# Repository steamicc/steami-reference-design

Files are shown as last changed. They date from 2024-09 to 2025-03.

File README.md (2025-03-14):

# STeaMi Reference Design

Welcome to the repository for the **STeaMi Reference Design**. This repository contains all the electronic and mechanical design files for the STeaMi learning board, a versatile and feature-rich platform for teaching programming and electronics.

## Overview
[STeaMi](https://www.steami.cc/) is an educational board aimed at introducing students, educators, and enthusiasts to the basics of programming, electronics, and STEM concepts. The board is designed with simplicity and versatility in mind, providing a powerful platform for learning through hands-on experience.



The **STeaMi board** is built around the **STM32WB55 microcontroller** and is designed to offer:

- **Connectivity:** BLE (Bluetooth Low Energy) communication capabilities.
- **Extensibility:** Integration options with Jacdac and Qwiic connectors.
- **Versatility:** A wide array of onboard sensors.
- **Compatibility:** Seamless integration with the **micro:bit ecosystem**, allowing educators to continue using existing materials while leveraging the advanced capabilities of STeaMi when needed.

This board is an essential tool for educators aiming to explore STEAM (Science, Technology, Engineering, Arts, Mathematics) education.

## Key Features

### Hardware
- **Microcontroller:** STM32WB55 with dual-core architecture (ARM Cortex-M4 and Cortex-M0+).
- **BLE Support:** Bluetooth Low Energy for IoT and wireless communication projects.
- **Connectors:**
  - **Jacdac:** For chaining external modules and simplifying connections.
  - **Qwiic:** For seamless sensor and peripheral integration.
- **Onboard Sensors:**
  - Environmental sensors (temperature, humidity, pressure).
  - Motion sensors (accelerometer, gyroscope, magnetometer).
  - Proximity, light, and other utility sensors.

### Compatibility
- **micro:bit Ecosystem:** Fully compatible, allowing educators to reuse existing peripherals and lessons.
- **Plug-and-play Design:** Simplifies adoption in classrooms and workshops.

### Mechanical Design
- Compact form factor, ensuring ease of use.
- Mounting options compatible with standard educational kits.

## Project Background
The STeaMi board was developed as part of the **I-NOVMICRO** project ([Learn more](https://campus-industriefutur-sud.com/i-novmicro/)) and the **MAGNETICS** project ([Learn more](https://www.magnetics.edu-up.fr/)). These initiatives aim to advance innovative tools for education and training.

## Repository Contents
- **Electronics Design Files:** Schematics, PCB layout files, and BOM.
- **Mechanical Design Files:** CAD models for the enclosure and mounting options.

## Getting Started
1. Clone this repository:
   ```bash
   git clone https://github.com/steamicc/steami-reference-design.git
   ```
2. Review the documentation folder for setup instructions.
3. Open the design files using your preferred CAD and PCB design tools.

## License
All resources in this repository are released under an open license and are protected under the stewardship of the **STeaMi Foundation**. See the `LICENSE` file for more details.

## Contributions
We welcome contributions to enhance the STeaMi board. Whether you’re fixing a bug, adding a feature, or improving documentation, feel free to submit a pull request.

## Resources
- [STeaMi Official Website](https://www.steami.cc/)

## Support
If you have any questions or need assistance, please open an issue in this repository or contact us via [STeaMi contact mail](mailto:contact@steami.cc).

---

Thank you for supporting STeaMi and STEAM education!

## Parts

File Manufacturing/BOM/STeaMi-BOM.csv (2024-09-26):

Description | Quantity | Designator | Manufacturer | Manufacturer Part Number | Part Number | Digikey | Farnell | Mouser | RS | Switch possibility | Layer
CAP CER 1µF 6,3V X5R 0402 | 11 | C1, C2, C10, C12, C31, C46, C47, C62, C63, C77, C80 | Taiyo Yuden | JMK105BJ105KV-F | 1µF-10%-6,3V-X5R-0402 |  |  | 963-JMK105BJ105KV-F |  | True | Bottom, Top
CAP CER 10nF 10V X7R 0402 | 1 | C13 | AVX | 0402ZC103KAT2A | 10nF-10%-10V-X7R-0402 |  |  | 581-0402ZC103KAT2A |  | True | Top
CAP CER 100pF 10V X7R 0402 | 1 | C15 | WURTH Electronics | 885012205001 | 100pF-10%-10V-X7R-0402 | 732-7496-1-ND | 2812288 | 710-885012205001 |  | True | Top
CAP CER 200mF 3,3V Supercap 6,8X11,7x1,8 | 1 | C17 | Elna America | DSK-3R3H204T614-H2L | 200mF-20%-3,3V-Supercap-6,8X11,7x1,8 | 604-1147-1-ND |  | 555-DSK3R3H204T614H2 |  | False | Top
CAP CER 4,7µF 6,3V X5R 0402 | 6 | C25, C32, C34, C55, C57, C86 | Murata | GRM155R60J475ME8D | 4,7µF-20%-6,3V-X5R-0402 | 490-5408-6-ND |  | 81-GRM155R60J475ME8D |  | True | Top, Bottom
CAP CER 15pF 10V C0G 0402 | 4 | C26, C27, C28, C29 | KEMET | C0402C150J8HACTU | 15pF-5%-10V-C0G-0402 |  | 3784148 | 80-C0402C150J8HACTU |  | True | Bottom
CAP CER 47µF 4V X5R 0603 | 2 | C3, C87 | Taiyo Yuden | AMK107BBJ476MA-RE | 47µF-20%-4V-X5R-0603 |  |  | 963-AMK107BBJ476MARE |  | True | Top
CAP CER 10µF 6,3V X5R 0402 | 6 | C4, C8, C52, C64, C83, C84 | Murata | GRM155R60J106ME15D | 10µF-20%-6,3V-X5R-0402 | 490-13238-1-ND | - | 81-GRM155R60J106ME5D | - | True | Top, Bottom
CAP CER 33pF 16V COG 0402 | 1 | C42 | WURTH Electronics | 885012005028 | 33pF-5%-16V-COG-0402 | 732-7444-1-ND |  | 710-885012005028 |  | True | Bottom
CAP CER 4,7µF 16V X5R 0402 | 2 | C44, C45 | Kyocera AVX | 0402YD475MAT2A | 4,7µF-20%-16V-X5R-0402 | 478-10788-1-ND |  | 581-0402YD475MAT2A |  | True | Top
CAP CER 100nF 6,3V X5R 0402 | 38 | C5, C9, C11, C14, C16, C18, C19, C20, C21, C22, C23, C24, C30, C33, C35, C36, C37, C38, C39, C40, C41, C43, C48, C49, C50, C51, C54, C56, C58, C69, C70, C71, C72, C75, C78, C79, C81, C82 | Kyocera AVX | 0402YD104KAT2A | 100nF-10%-6,3V-X5R-0402 | 478-1126-1-ND |  | 581-0402YD104K |  | True | Top, Bottom
CAP CER 220nF 6,3V X7R 0603 | 1 | C53 | KEMET | C0603C224K9RACTU | 220nF-10%-6,3V-X7R-0603 | 399-9046-1-ND |  | 80-C0603C224K9R |  | True | Bottom
CAP CER 470pF 25V X7R 0402 | 1 | C6 | Yageo | AC0402KRX7R8BB471 | 470pF-10%-25V-X7R-0402 |  |  | 603-AC402KRX7R8BB471 |  | True | Top
CAP CER 15µF 25V TANT 1210 | 1 | C7 | Panasonic | 25TQC15MYFB | 15µF-20%-25V-TANT-1210 | P16204CT-ND | 2982721 | 667-25TQC15MYFB |  | True | Top
CAP CER 22pF 16V COG 0402 | 2 | C73, C74 | Murata | GJM0225C1C220JB01L | 22pF-5%-16V-COG-0402 | - | - | 80-C0402C220J4GAUTO | - | True | Bottom
CAP CER 10pF 10V COG 0402 5% | 1 | C85 | WURTH Electronics | 885012005007 | 10pF-5%-10V-COG-0402 |  | 2533781 | 710-885012005007 |  | True | Top
Suppresseurs ESD / diodes TVS WE-TVS High Speed 5uA 5VDC 4+1 | 1 | D1 | Wurth | WE-TVS_824015 | WE-TVS_824015 |  |  | 710-824015 |  | False | Bottom
ESD Suppressors / TVS Diodes Transient Voltage Suppressor PP | 5 | D2, D4, D10, D13, D24 | Diodes Incorporated | D5V0H1B2LP-7B | D5V0H1B2LP-7B | D5V0H1B2LP-7BDICT-ND |  | 621-D5V0H1B2LP-7B |  | False | Top, Bottom
Diode Schottky 40 V 1A Montage en surface SDO-323HE | 1 | D25 | OnSemiconductor | SS14HE | SS14HE | 512-SS14HE | 2929794 |  |  | False | Top
Diode 40 V 100mA Surface Mount 0402C/SOD-923F | 2 | D26, D27 | Comchip | CDBQR0140R-HF | CDBQR0140R-HF | CDBQR0140R-HF-ND |  |  |  | False | Bottom
Diode Schottky 40 V 1A Montage en surface SOD-123 | 1 | D3 | Torex Semiconductor | XBS104S14R-G | XBS104S14R-G |  |  | 865-XBS104S14R-G |  | False | Top
Diode Schottky 30 V 1A Montage en surface SOD-123 | 4 | D5, D6, D7, D15 | SMC diode solutions | MBR130HWTR | MBR130HWTR | 1655-1437-1-ND |  |  |  | False | Top, Bottom
Suppresseurs ESD / diodes TVS LOW CAP SNAPBACK ESD PROT | 13 | D8, D9, D11, D12, D14, D16, D17, D18, D19, D20, D21, D22, D23 | OnSemiconductor | ESD8351XV2T1G | ESD8351XV2T1G |  | 2770609 | 863-ESD8351XV2T1G |  | False | Bottom, Top
Fusible 50V 1,25 A Slow blow | 1 | F1 | Bourns | SF-0603SP125-2 | SF-0603SP125-2 |  |  | 652-SF-0603S125-2 |  | False | Top
Chip Ferrite Bead 300 ohm à 100MHZ | 1 | FB1 | WURTH | 742792641 | 742792641 |  |  | 710-742792641 |  | False | Bottom
Chip Ferrite Bead 330 ohm à 100MHZ | 1 | FB2 | MURATA | BLM18RK102SN1D | BLM18RK102SN1D | 490-5228-1-ND |  | 81-BLM18RK102SN1D |  | False | Bottom
CONN header smd 2 positions 1,25 mm | 1 | J1 | Amphenol | 10114830-10102LF | 1011483010102LF |  |  | 609-5378-1-ND |  | False | Bottom
Connector micro USB Bottom-SMT No Peg | 1 | J2 | GCT | USB3080-30-00-A | USB3080-30-00-A |  |  | 640-USB3080-30-00-A |  | False | Bottom
Connecteur, embase Montage en surface à angle droit 4 positions (2,00mm) | 2 | J3, J4 | JST | S4B-PH-SM4-TB(LF)(SN) | S4B-PH-SM4-TB(LF)(SN) | 455-1751-1-ND | 9492631 |  |  | False | Bottom
FFC/FPC connector 0,50 Pitch Slider Right angle TOP Contact | 1 | J7 | Molex | 52435-2471 | 52435-2471 |  |  | 538-52435-2471 | 52435-2471-TR250 | False | Top
Common mode chokes | 1 | L1 | WURTH | 744230900 | 744230900 | 732-2582-1-ND |  |  |  | False | Bottom
Fixed Inductor 10µH ± 20% 1,4A 3x3x1,2mm | 1 | L2 | TDK | VLS3012CX-2R2M-1 | 2,2µH-20%-1,89A-74 mOhms |  |  | 810-VLS3012CX-2R2M-1 |  | False | Top
Fixed Inductor 10µH ± 20% 1,4A 5,8mm | 1 | L3 | Wurth | 74404043150A | 15µH-20%-0,84-132 mOhms% | 732-10760-1-ND |  | 710-74404043150A |  | False | Top
Fixed Inductor 10µH µH ± 20% 0,1A 0805 | 1 | L4 | Murata Electronics | LQM21FN100M70L | 10µH-20%-0,1A-600mOhm |  |  | 81-LQM21FN100M70L |  | False | Bottom
Fixed Inductor 10µH ± 20% 1,12A 3x3x1,2mm | 1 | L5 | TDK | VLS3012CX-100M-1 | 10µH-20%-1,12A-324mOhms |  | 3212546 | 810-VLS3012CX-100M-1 |  | False | Top
DEL standard - CMS WL-SMCW SMDMono TpVw Waterclr 0603 RED | 1 | LED2 | WURTH | 150060RS75000 | 150060RS75000 |  |  | 710-150060RS75000 |  | False | Top
DEL standard - CMS WL-SMCW SMDMono TpVw Waterclr 0603 Blue | 2 | LED3, LED6 | WURTH | 150060BS75000 | 150060BS75000 |  |  | 710-150060BS75000 |  | False | Top
LED GREEN 2V 20mA 0603 SMD | 1 | LED4 | WURTH | 150060VS75000 | 150060VS75000 |  |  | 710-150060VS75000 |  | False | Top
LED BI Green Red 2mm x 1,25mm SMD | 1 | LED5 | Kingbright | APHBM2012LSURKZGKC | APHBM2012LSURKZGKC |  |  | 604-APHBM2012LSURKZG |  | False | Top
DEL standard - CMS WL-SFTW SMD TOP SMD 5050 RGB | 1 | LED7 | WURTH | 150505M173300 | 150505M173300 | 150505M173300 |  | 710-150505M173300 |  | False | Top
Speakers & Transducers SURFACE MOUNT TRANSDUCER 3.6 VP-P | 1 | LS1 | PUI Audio Inc | SMT-0825-S-HT-R | SMT-0825-S-HT-R | 668-SMT-0825-S-HT-RCT-ND |  | 665-SMT0825SHTR |  | False | Bottom
RES CMS 1,5K1%-0,0625W-0402 ±100ppm/°C | 1 | R100 | Yageo | RC0402FR-071K5L | 1,5K-1%-0,0625W-0402 | 311-1.50KLRDKR-ND | 2693583 | 603-RC0402FR-071K5L |  | True | Bottom
RES CMS 100K1%-0,063W-0402 ±100ppm/°C | 1 | R116 | TE Connectivity | CRG0402F100K | 100K-1%-0,063W-0402 |  |  |  | 667-8977 | True | Top
RES CMS 10K1%-0,0625W-0402 ±100ppm/°C | 6 | R12, R19, R26, R28, R91, R96 | Yageo | AC0402FR-1310KL | 10K-1%-0,0625W-0402 |  |  | 603-AC0402FR-1310KL |  | True | Bottom, Top
RES CMS 1,6K1%-0,1W-0402 ±100ppm/°C | 2 | R13, R14 | Panasonic | ERJ-2RKF 1601X | 1,6K-1%-0,1W-0402 |  |  | 667-ERJ-2RKF1601X |  | True | Bottom
RES CMS 4,7K5%-0,0625W-0402 ±100ppm/°C | 9 | R15, R16, R33, R34, R35, R36, R37, R38, R39 | Yageo | AC0402JR-074K7L | 4,7K-5%-0,0625W-0402 | 311-4.7KLBDKR-ND | 3495221 | 603-AC0402JR-074K7L |  | True | Bottom, Top
RES CMS 10m1%-0,2W-0402 ±0ppm/°C | 1 | R18 | Panasonic | ERJ-2LWFR010X | 10m-1%-0,2W-0402 |  |  | 667-ERJ-2LWFR010X |  | False | Bottom
RES CMS 100K5%-0,0625W-0402 ±100ppm/°C | 8 | R2, R5, R8, R17, R69, R99, R105, R110 | Yageo | RC0402JR-07100KL | 100K-5%-0,0625W-0402 | 311-100KJRCT-ND | 9233008 |  |  | True | Bottom
RES CMS 100R5%-0,0625W-0402 ±100ppm/°C | 11 | R21, R40, R41, R42, R43, R44, R45, R46, R65, R93, R97 | Yageo | RC0402JR-07100RL | 100R-5%-0,0625W-0402 | 311-100JRCT-ND | 9232648 |  |  | True | Top, Bottom
RES CMS 1M1%-0,125W-0402 ±0ppm/°C | 2 | R22, R56 | Yageo | RC0402FR-7W1ML | 1M-1%-0,125W-0402 |  |  | 603-RC0402FR-7W1ML |  | True | Top
RES CMS 178K1%-0,1W-0402 ±25ppm/°C | 1 | R23 | Panasonic | ERJ-2RKF1783X | 178K-1%-0,1W-0402 |  |  | 667-ERJ-2RKF1783X |  | True | Top
RES CMS 105K0,5%-0,1W-0402 ±0ppm/°C | 1 | R27 | Panasonic | ERJ-2RKF1053X | 105K-0,5%-0,1W-0402 |  | 2302841 | 667-ERJ-2RKF1053X |  | True | Top
RES CMS 15R0,5%-1W-1206 ±0ppm/°C | 1 | R31 | Susumu | HRG3216Q-15R0-D-T1 | 15R-0,5%-1W-1206 | 408-1885-1-ND |  | 754-HRG3216Q15R0DT1 |  | True | Top
RES CMS 0R5%-0,0625W-0402 | 27 | R4, R6, R10, R11, R20, R24, R25, R30, R48, R49, R50, R52, R60, R62, R68, R71, R72, R73, R74, R79, R83, R94, R95, R111, R112, R113, R114 | Yageo | RC0402JR-100RL | 0R-5%-0,0625W-0402 |  |  | 603-RC0402JR-100RL |  | True | Bottom, Top
RES CMS 220R5%-0,1W-0402 ±10ppm/°C | 1 | R47 | Panasonic | ERJ-2GEJ221X | 220R-5%-0,1W-0402 | P220JCT-ND | 2692419 | 667-ERJ-2GEJ221X |  | True | Bottom
RES CMS 470R5%-0,1W-0402 ±200ppm/°C | 1 | R53 | Panasonic | ERJ-2GEJ471X | 470R-5%-0,1W-0402 |  |  | 667-ERJ-2GEJ471X |  | True | Bottom
RES CMS 10R1%-0,0625W-0402 ±200ppm/°C | 6 | R54, R64, R66, R67, R106, R108 | Yageo | RC0402FR-1010RL | 10R-1%-0,0625W-0402 |  |  | 603-RC0402FR-1010RL |  | True | Top
RES CMS 120R1%-0,0625W-0402 ±200ppm/°C | 2 | R55, R58 | Yageo | AC0402FR-07120RL | 120R-1%-0,0625W-0402 | YAG3440CT-ND |  | 603-AC0402FR-07120RL |  | True | Top
RES CMS 1,15M1%-0,1W-0402 ±0ppm/°C | 1 | R57 | KOA Speer | RK73H1ETTP1154F | 1,15M-1%-0,1W-0402 | 2019-RK73H1ETTP1154FCT-ND |  | 660-RK73H1ETTP1154F |  | True | Top
RES CMS 324K1%-0,0625W-0402 ±100ppm/°C | 1 | R59 | Yageo | AC0402FR-07324KL | 324K-1%-0,0625W-0402 | 13-AC0402FR-07324KLCT-ND |  | 603-AC0402FR-07324KL |  | True | Top
RES CMS 47R1%-0,0625W-0402 ±100ppm/°C | 1 | R61 | Yageo | RC0402FR-0747RL | 47R-1%-0,0625W-0402 | 311-47.0LRCT-ND |  | 603-RC0402FR-0747RL | 198-7801 | True | Top
RES CMS 100K1%-0,1W-0402 ±100ppm/°C | 3 | R63, R102, R103 | Panasonic | ERJ-2RKF1003X | 100K-1%-0,1W-0402 |  |  | 667-ERJ-2RKF1003X |  | True | Bottom
RES CMS 0R 1% 0,1W 0603 ±100ppm/°C | 1 | R81 | Vishay | CRCW06030000Z0EAC | 0R-1%-0,1W-0603 | 541-4012-1-ND | - | 71-CRCW06030000Z0EAC | - | True | Bottom
RES CMS 22R0,5%-0,0625W-0402 ±100ppm/°C | 1 | R86 | Panasonic | ERJ2RKD22R0X | 22R-0,5%-0,0625W-0402 |  |  | 667-ERJ-2RKD22R0X |  | True | Bottom
RES CMS 100K1%-0,1W-0603 ±100ppm/°C | 1 | R89 | Yageo | RC0603FR-07100KL | 100K-1%-0,1W-0603 |  |  | RC0603FR-07100KL |  | True | Bottom
RES CMS NI0%-0W-0402 ±100ppm/°C | 2 | R90, R101 | NC | NC | NC-0%-0W-0402 | - | - | - | - | True | Bottom
RES CMS 36K1%-0,0625W-0402 ±100ppm/°C | 1 | R98 | Yageo | RC0402FR-0736KL | 36K-1%-0,0625W-0402 | 311-36.0KLRCT-ND |  | 603-RC0402FR-0736KL |  | True | Bottom
Surface Mounting Switch | 1 | SW1 | C&K | PTS636 SM25J SMTR LFS | PTS636 SM25J SMTR LFS | CKN12325-1-ND |  | 611-PTS636SM25JSMTRL |  | False | Bottom
4-direction type with center-push function | 1 | SW2 | ALPS | SKRHABE010 | SKRHABE010 |  |  | 688-SKRHAB |  | False | Top
Interrupteurs de contact 50mA 12VDC, 1.8N 3.8mm H, G leads | 3 | SW3, SW4, SW5 | C&K | PTS647SM38SMTR2LFS | PTS647SM38SMTR2LFS |  |  | 611-PTS647SM38SMTR2L |  | False | Top
Small-Signal-Transitor MOSFET N | 2 | T1, T2 | Infineon | BSS119N-H6327 | BSS119N | BSS119NH6327XTSA1CT-ND | - | 726-BSS119NH6327 | - | False | Bottom
Transistors bipolaires - BJT SS SOT23 NPN 40V | 1 | T3 | On Semiconductor | MMBT2222A-7-F | MMBT2222A | MMBT2222A-FDICT-ND | 1773626 |  |  | False | Bottom
MOSFET N/P-CH 60V/50V SOT363 | 1 | T4 | Diodes Incorporated | BSS8402DW-7-F | BSS8402DW-7-F | BSS8402DW-FDIDKR-ND |  |  |  | False | Bottom
Standalone 1 cell 1,5A batterry with PowerPath | 1 | U1 | Texas Instruments | BQ24075RGT | BQ24075RGT |  |  | 595-BQ24075RGTR |  | False | Bottom
Accéléromètre, gyroscope, température, 6 axes Anturi I²C, SPI Sortie | 1 | U10 | STMicroelectronics | ISM330DLCTR | ISM330DLCTR | 497-17583-2-ND |  |  |  | False | Bottom
SENSOR OPTICAL 4M I2C | 1 | U11 | STMicroelectronics | VL53L1CXV0FY/1 | VL53L1X | 497-17764-1-ND |  | 511-VL53L1CXV0FY/1 |  | False | Top
Capteur de pression 3,77PSI ~ 18,27PSI (26kPa ~ 126kPa) Absolu 24 b 10-WFLGA | 1 | U12 | Wurth Elektronik | 2511020213301 | 2511020213301 | 1917-2511020213301CT-ND |  |  |  | False | Top
Humidité, température Capteur I²C, SPI Sortie | 1 | U13 | Wurth Elektronik | 2525020210001 | 2525020210001 | 1917-2525020210001CT-ND |  |  |  | False | Bottom
Capteurs optiques Ambiant 560nm I²C Module 8-SMD | 1 | U15 | Broadcom Limited | APDS-9960 | APDS-9960 | 516-3480-1-ND |  | 630-APDS-9960 |  | False | Top
ARM® Cortex®-M3 STM32F1 Microcontrôleurs IC 32-Bit 72MHz 128Ko (128K x 8) FLASH | 1 | U17 | STMicroelectronics | STM32F103CBT6 | STM32F103CBT6 | 497-6288-ND |  | 511-STM32F103CBT6 |  | False | Bottom
PMIC - Régulateurs de tension - Linéaires Positif Fixe 1 Sortie 150mA SOT-23-5 | 1 | U19 | STMicroelectronics | LD3985M33R | LD3985M33R | 497-3504-1-ND |  | 6868802P |  | False | Bottom
LiCoO2, Li-Ion, Indicateur de charge batterie, alimentation 2.45 V à 4.5 V, interface I2C, SON-12 | 1 | U2 | Texas Instruments | BQ27441DRZR-G1A | BQ27441DRZR-G1A | 296-37271-1-ND | 2400942 | 595-BQ27441DRZR-G1A |  | False | Bottom
FLASH - NOR Mémoire IC 64Mb (8M x 8) SPI - I/O quadruple, QPI, DTR 133MHz 6ns 8-WSON (6x5) | 1 | U20 | Winbond | W25Q64JVZPIM | W25Q64JVZPIM | 256-W25Q64JVZPIM-ND |  |  |  | False | Bottom
5,5V Low loss Power distribution switch | 1 | U21 | DIOO Microcircuits | DIO7003LEST5 | DIO7003LEST5 |  |  | 453-DIO7003LEST5 |  | False | Bottom
Survolteur Régulateur à découpage IC Positif Réglable 1,23V 1 Sortie 75mA (Commutateur) SC-74A, SOT-753 | 1 | U22 | Diodes Incorporated | AP3015AKTR-G1 | AP3015AKTR-G1 | AP3015AKTR-G1DICT-ND |  |  | 8287438 | False | Top
High Efficient single inductor buck-boost converter with 1,8-A switches ajustable | 1 | U3 | Texas Instruments | TPS63000DRCT | TPS63000 |  |  | 595-TPS63000DRCR |  | False | Top
Simple Switcher 24Vout 2,1A Step-Up SOT-23 | 1 | U4 | Texas Instruments | LMR62421XMF_NOPB | LMR62421XMF_NOPB |  |  | 926-LMR62421XMF/NOPB |  | False | Top
MEMS audio sensor omnidirectional digital microphone dor industrial application | 1 | U5 | STMicroelectronics | IMP34DT05 | IMP34DT05 |  |  | 511-IMP34DT05TR |  | False | Top
MCU 32bit, STM32WB55RX-M4, 256 Kb to 1Mb Flash 128 to 256kB SRAM 64MHz Bluetooth 5.2, VFQFPN68 | 1 | U6 | STMicroelectronics | STM32WB55RG | STM32WB55RG |  |  | 511-STM32WB55RGV6 |  | False | Bottom
Centre 2,45GHz fréquence Passe-bas Filtres RF (Fréquence radio) 100MHz Bande passante 1,1dB 6-SMD, sans plomb | 1 | U7 | STMicroelectronics | MLPF-WB55-01E3 | MLPF-WB55-01E3 | 497-19088-1-ND |  | 511-MLPF-WB55-01E3 |  | False | Bottom
Interface - Extensions d'E/S 8B I/O Expander I2C interface | 1 | U8 | Microchip | MCP23009-E/MG | MCP23009-E/MG |  |  | 579-MCP23009-E/MG |  | False | Bottom
magnétorésistif Capteur X, Y, Z axe 12-LGA (2x2) | 1 | U9 | STMicroelectronics | LIS2MDLTR | LIS2MDLTR | 497-17588-2-ND |  |  |  | False | Bottom
QUARTZ 32MHz 9pF 10 ppm | 1 | X1 | Wurth | 830103552209 | 830103552209 | 1923-830103552209CT-ND |  | 710-830103552209 |  | False | Bottom
QUARTZ 32Khz 12pF 30 ppm | 1 | X2 | Wurth | 830062558 | 830062558 | 732-830062558CT-ND |  | 710-830062558 |  | False | Bottom
QUARTZ 8MHz 12pF 20 ppm | 1 | X4 | Wurth | 830108313809 | 830108313809 | 732-830108313809CT-ND |  | 710-830108313809 |  | False | Bottom
Non câblé
NI | 17 | R3, R7, R9, R29, R32, R51, R70, R75, R76, R77, R78, R82, R85, R92, R107, R109, R115 | - | - | NI-1%-0,1W-0603 | - | - | - | - | True | Bottom, Top
Embase FTS 10 point 1,27 mm vertical | 1 | J8 | SAMTEC | FTS-105-01-F-D | FTS-105-01-F-D | SAM9420-ND |  | 200-FTS10501FD |  | False | Top
CONN HEADER VERT 3POS 1.27MM | 1 | J9 | SAMTEC | FTS-103-01-F-S | FTS-103-01-F-S | 612-FTS-103-01-F-S-ND |  |  |  | False | Bottom
RES CMS NI0%-0W-0402 ±100ppm/°C | 2 | R90, R101 | NC | NC | NC-0%-0W-0402 | - | - | - | - | True | Bottom

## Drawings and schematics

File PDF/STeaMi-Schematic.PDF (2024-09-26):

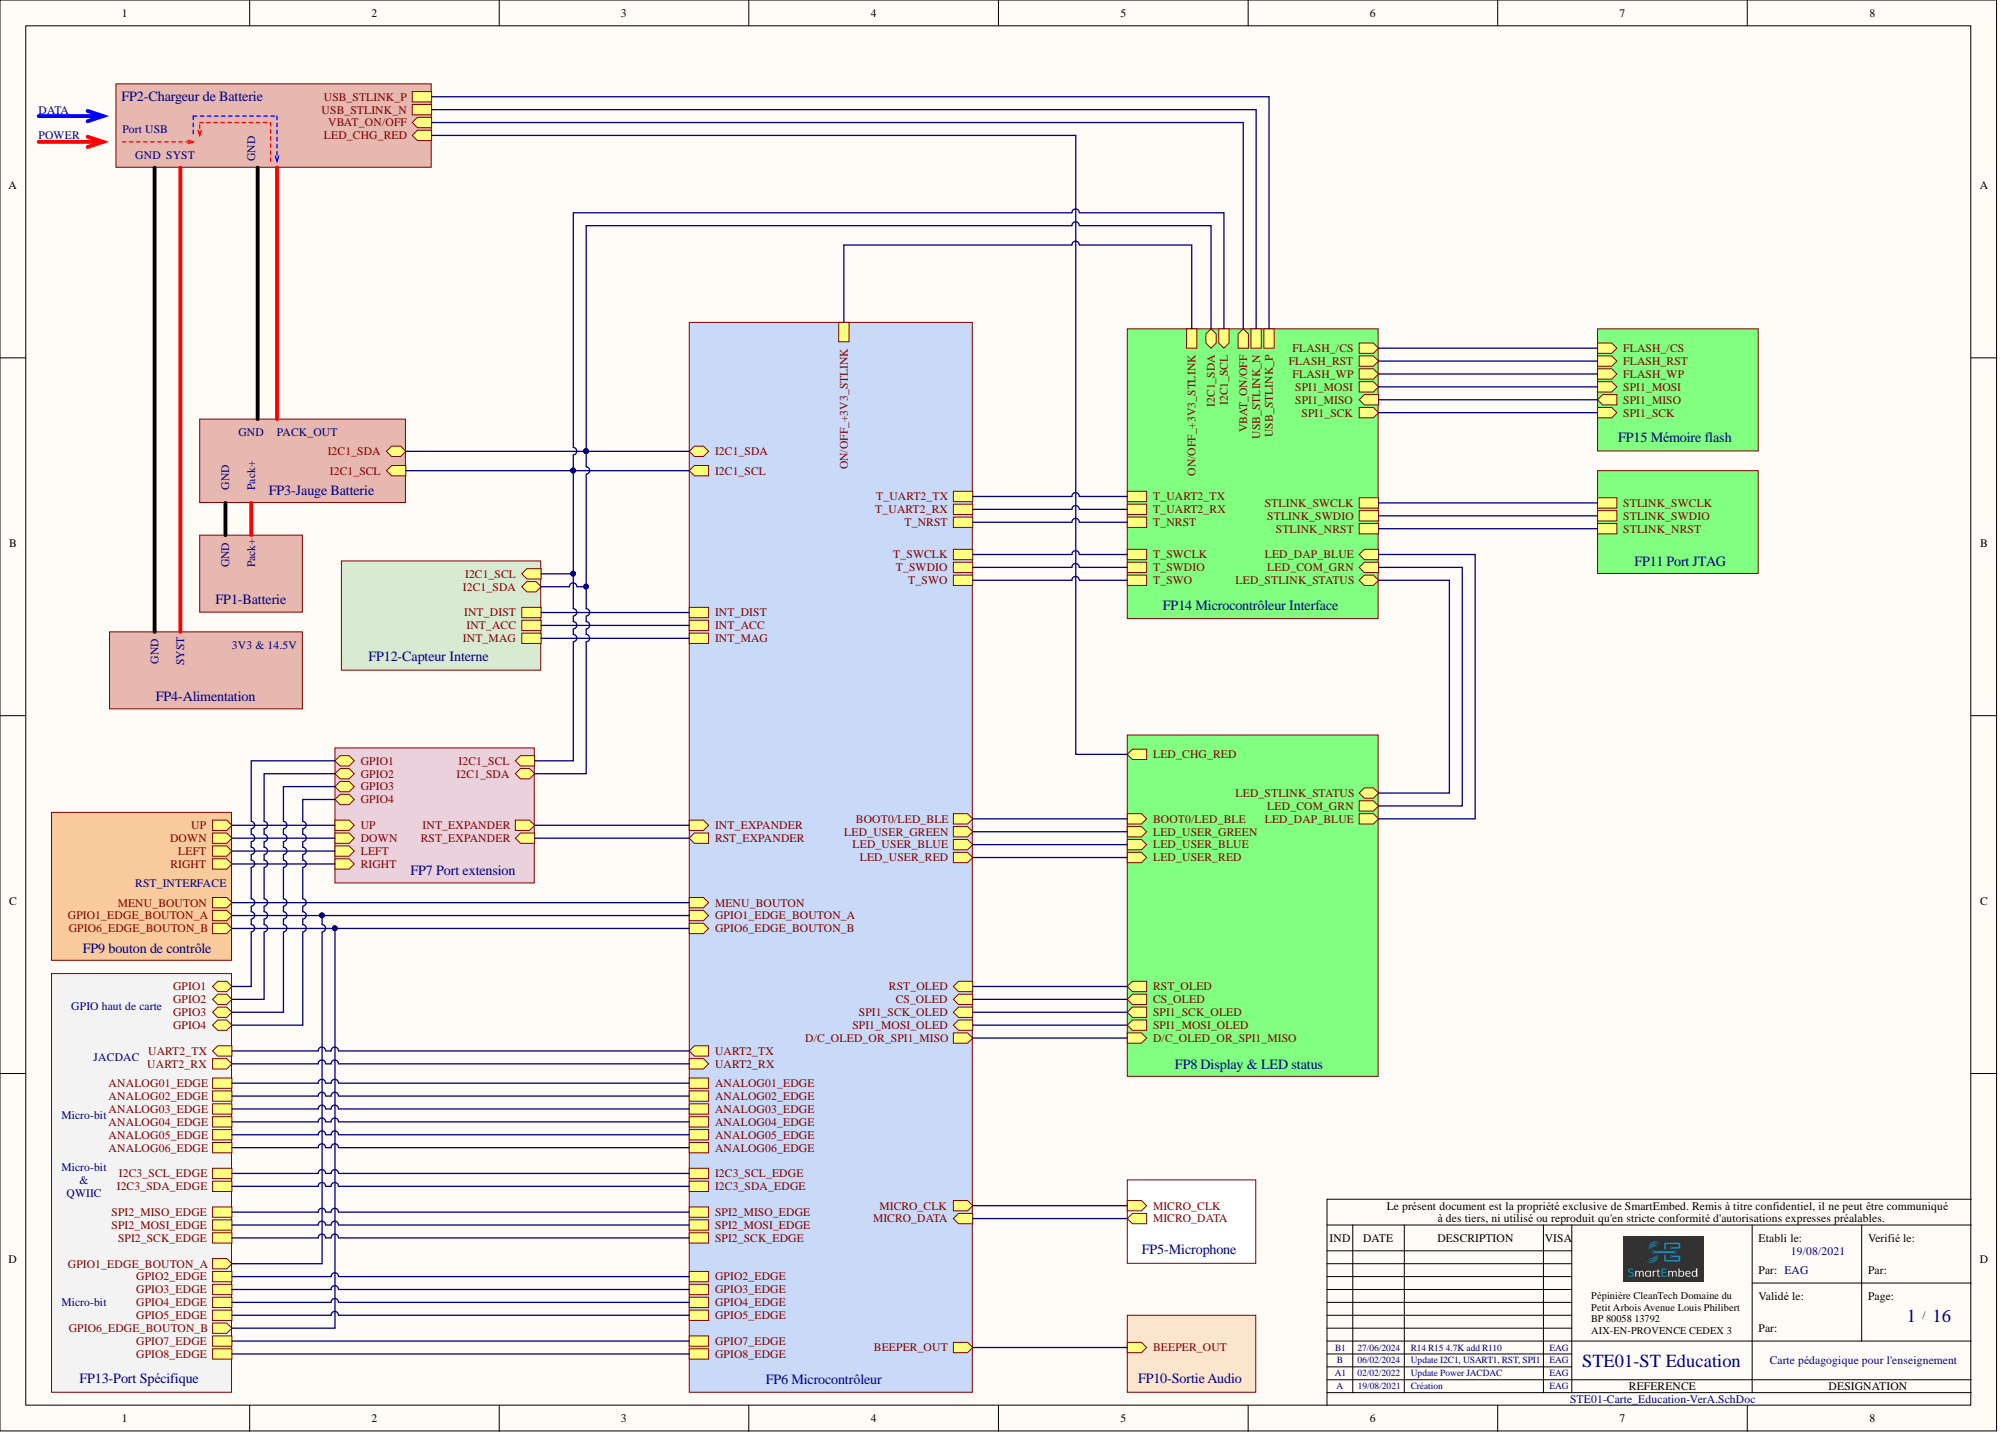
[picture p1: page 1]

GPIO1 GPIO2 GPIO haut de carte GPIO3 GPIO4 UART2_TX JACDAC UART2_RX QWIIC GPIO1_EDGE_BOUTON_A GPIO6_EDGE_BOUTON_B FP13-Port Spécifique

Le présent document est la propriété exclusive de SmartEmbed. Remis à titre confidentiel, il ne peut être communiqué

à des tiers, ni utilisé ou reproduit qu'en stricte conformité d'autorisations expresses préalables.

Pépinière CleanTech Domaine du
Petit Arbois Avenue Louis Philibert
AIX-EN-PROVENCE CEDEX 3

Validé le: Par: | Page: /

B1 | 27/06/2024 | R14 R15 4.7K add R110 | EAG | STE01-ST Education | Carte pédagogique pour l'enseignement
B | 06/02/2024 | Update I2C1, USART1, RST, SPI1 | EAG
A1 | 02/02/2022 | Update Power JACDAC | EAG
A | 19/08/2021 | Création | EAG | REFERENCE | DESIGNATION

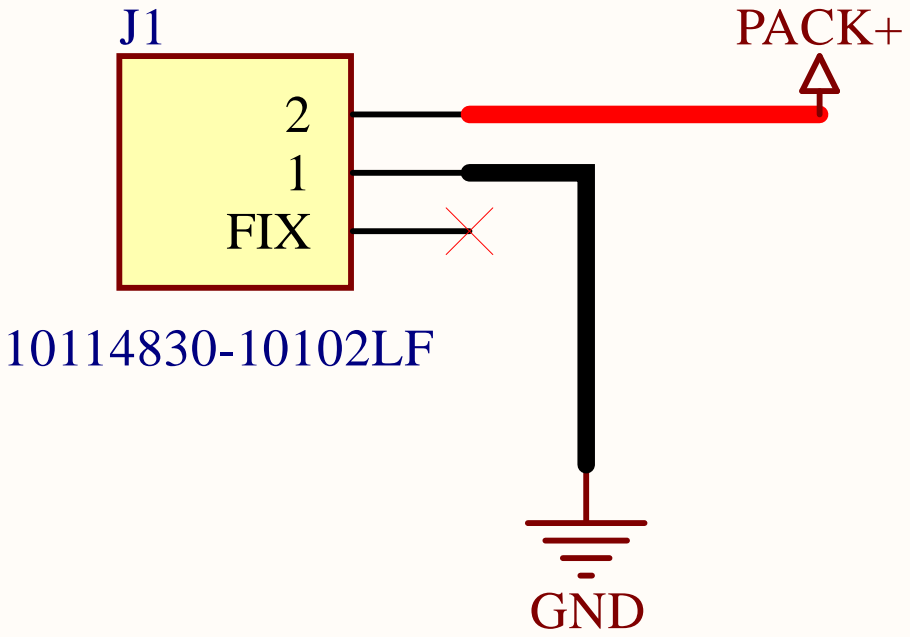
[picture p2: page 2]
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

à des tiers, ni utilisé ou reproduit qu'en stricte conformité d'autorisations expresses préalables.

Pépinière CleanTech Domaine du
Petit Arbois Avenue Louis Philibert

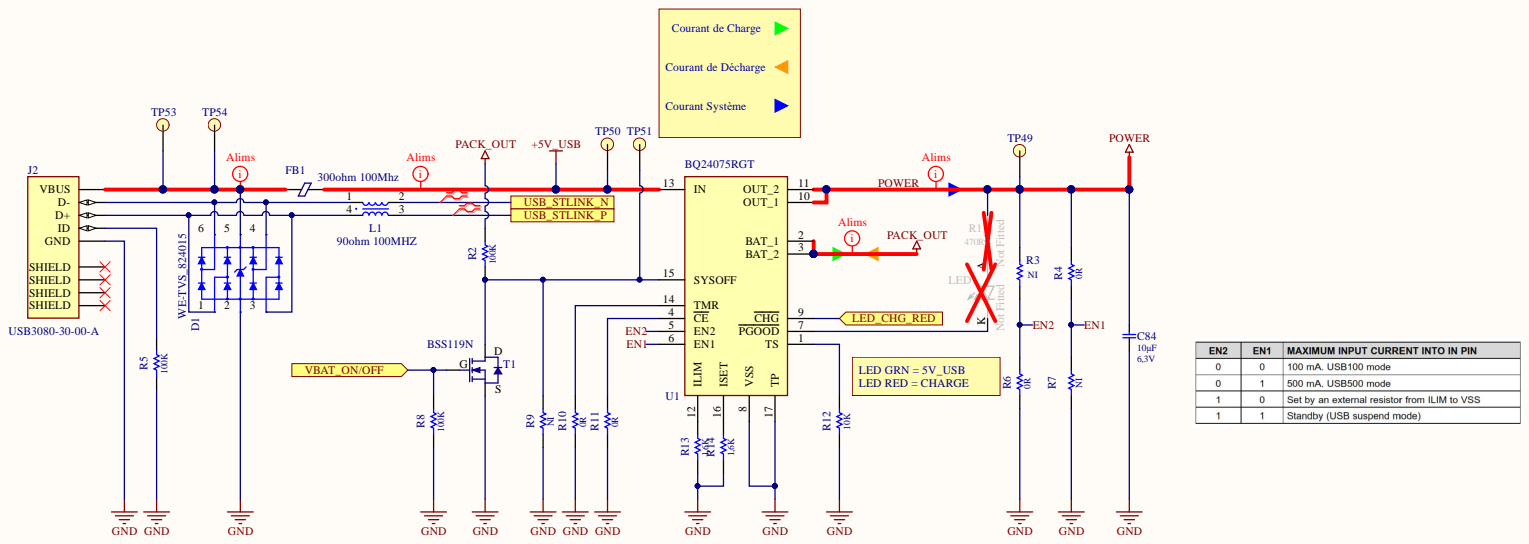
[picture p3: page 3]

1 4

Val i d é le: | Page:

B 1 | 27/06/2024 | R14 R15 4.7K add R | EAG | STE0 1-ST Ed ucatio n | Carte p é dag o g i q ue p o ur l'en sei g nemen t
B | 06/02/2024 | Update I2C1, USART1, R S T , S P I | EAG
A1 | 02/02/2022 | Update Powe r JACDAC | EAG
A | 19/08/2021 | C r é ation | EAG | REFERE NCE | D ESIG N ATIO N

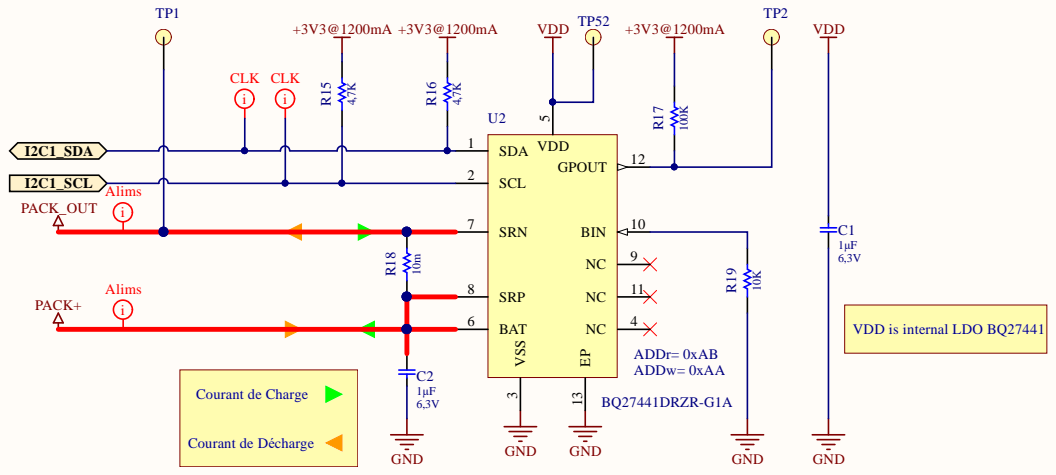
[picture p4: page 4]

Val i d é le: | Page: N4

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

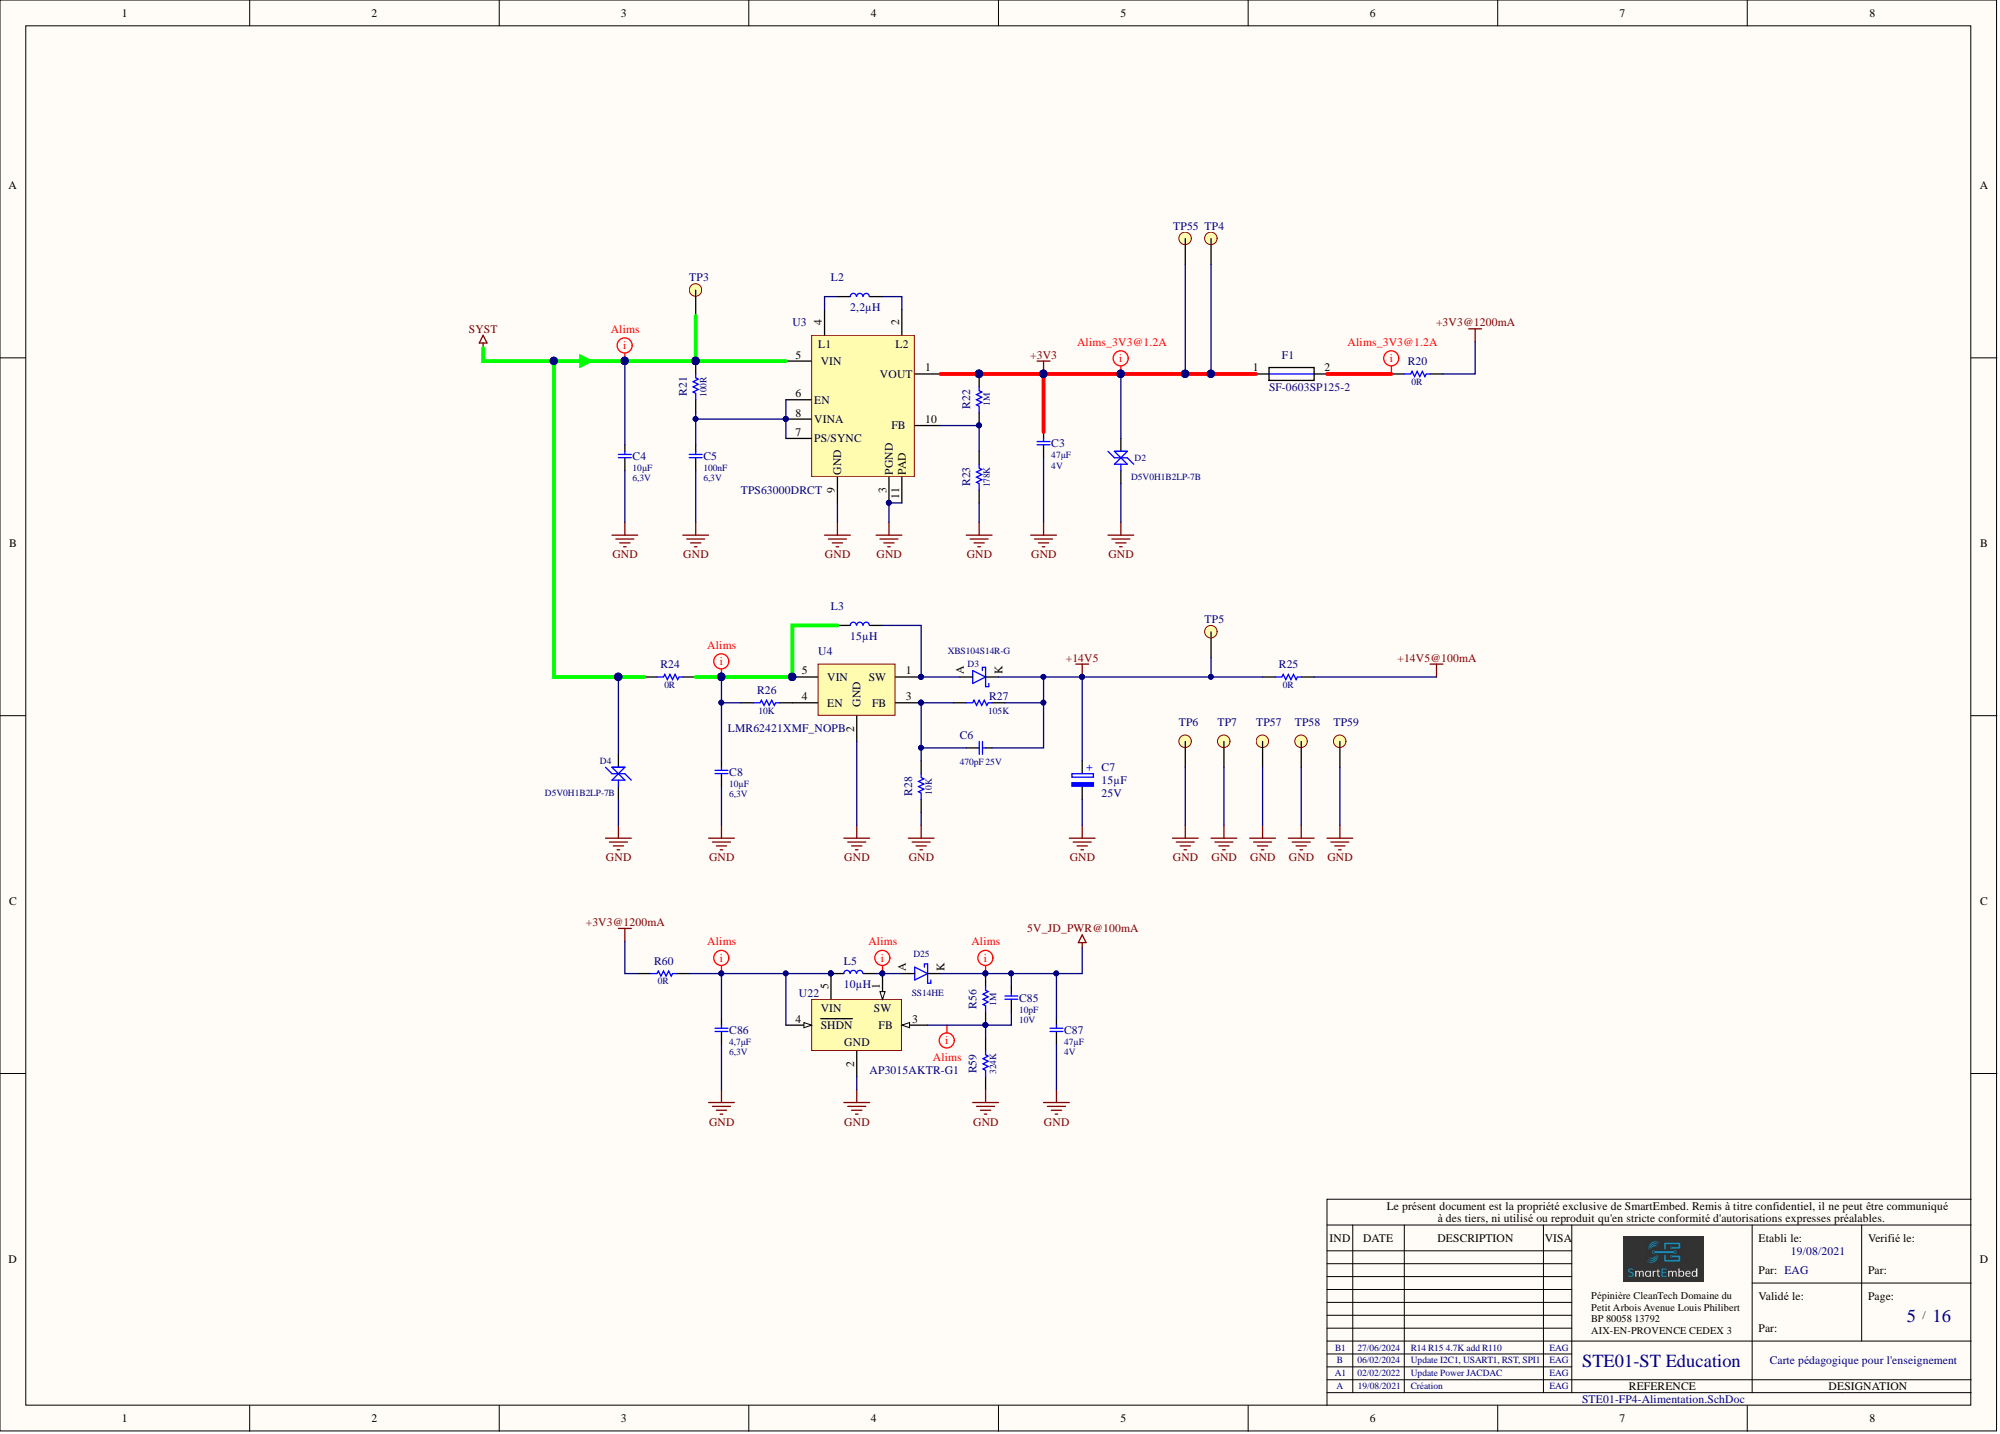
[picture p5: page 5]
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

à des tiers, ni utilisé ou reproduit qu'en stricte conformité d'autorisations expresses préalables.

Pépinière CleanTech Domaine du
Petit Arbois Avenue Louis Philibert

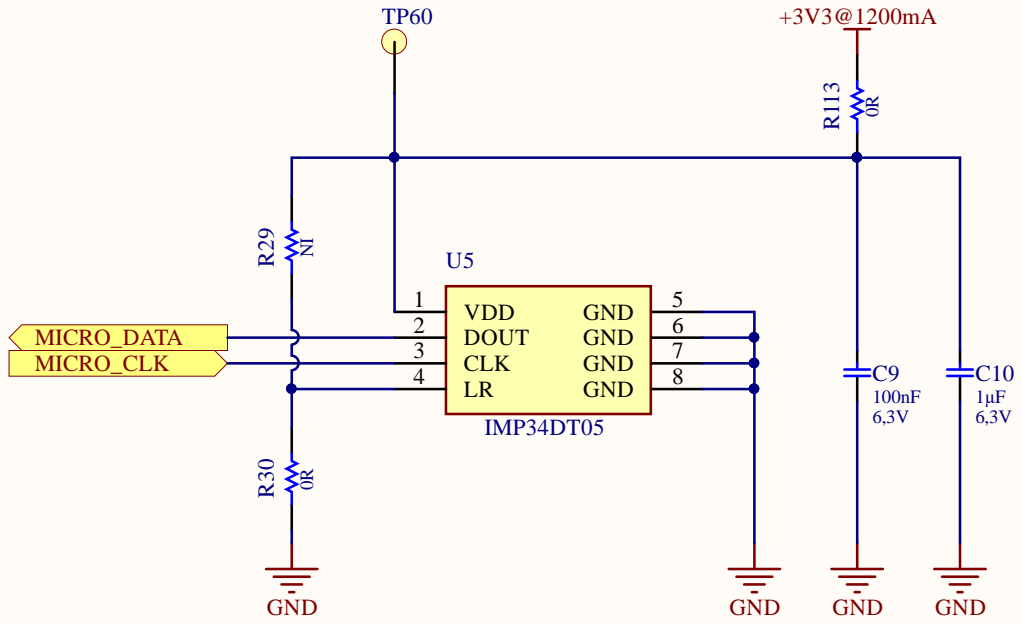
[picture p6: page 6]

Val i d é le: | Page:

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

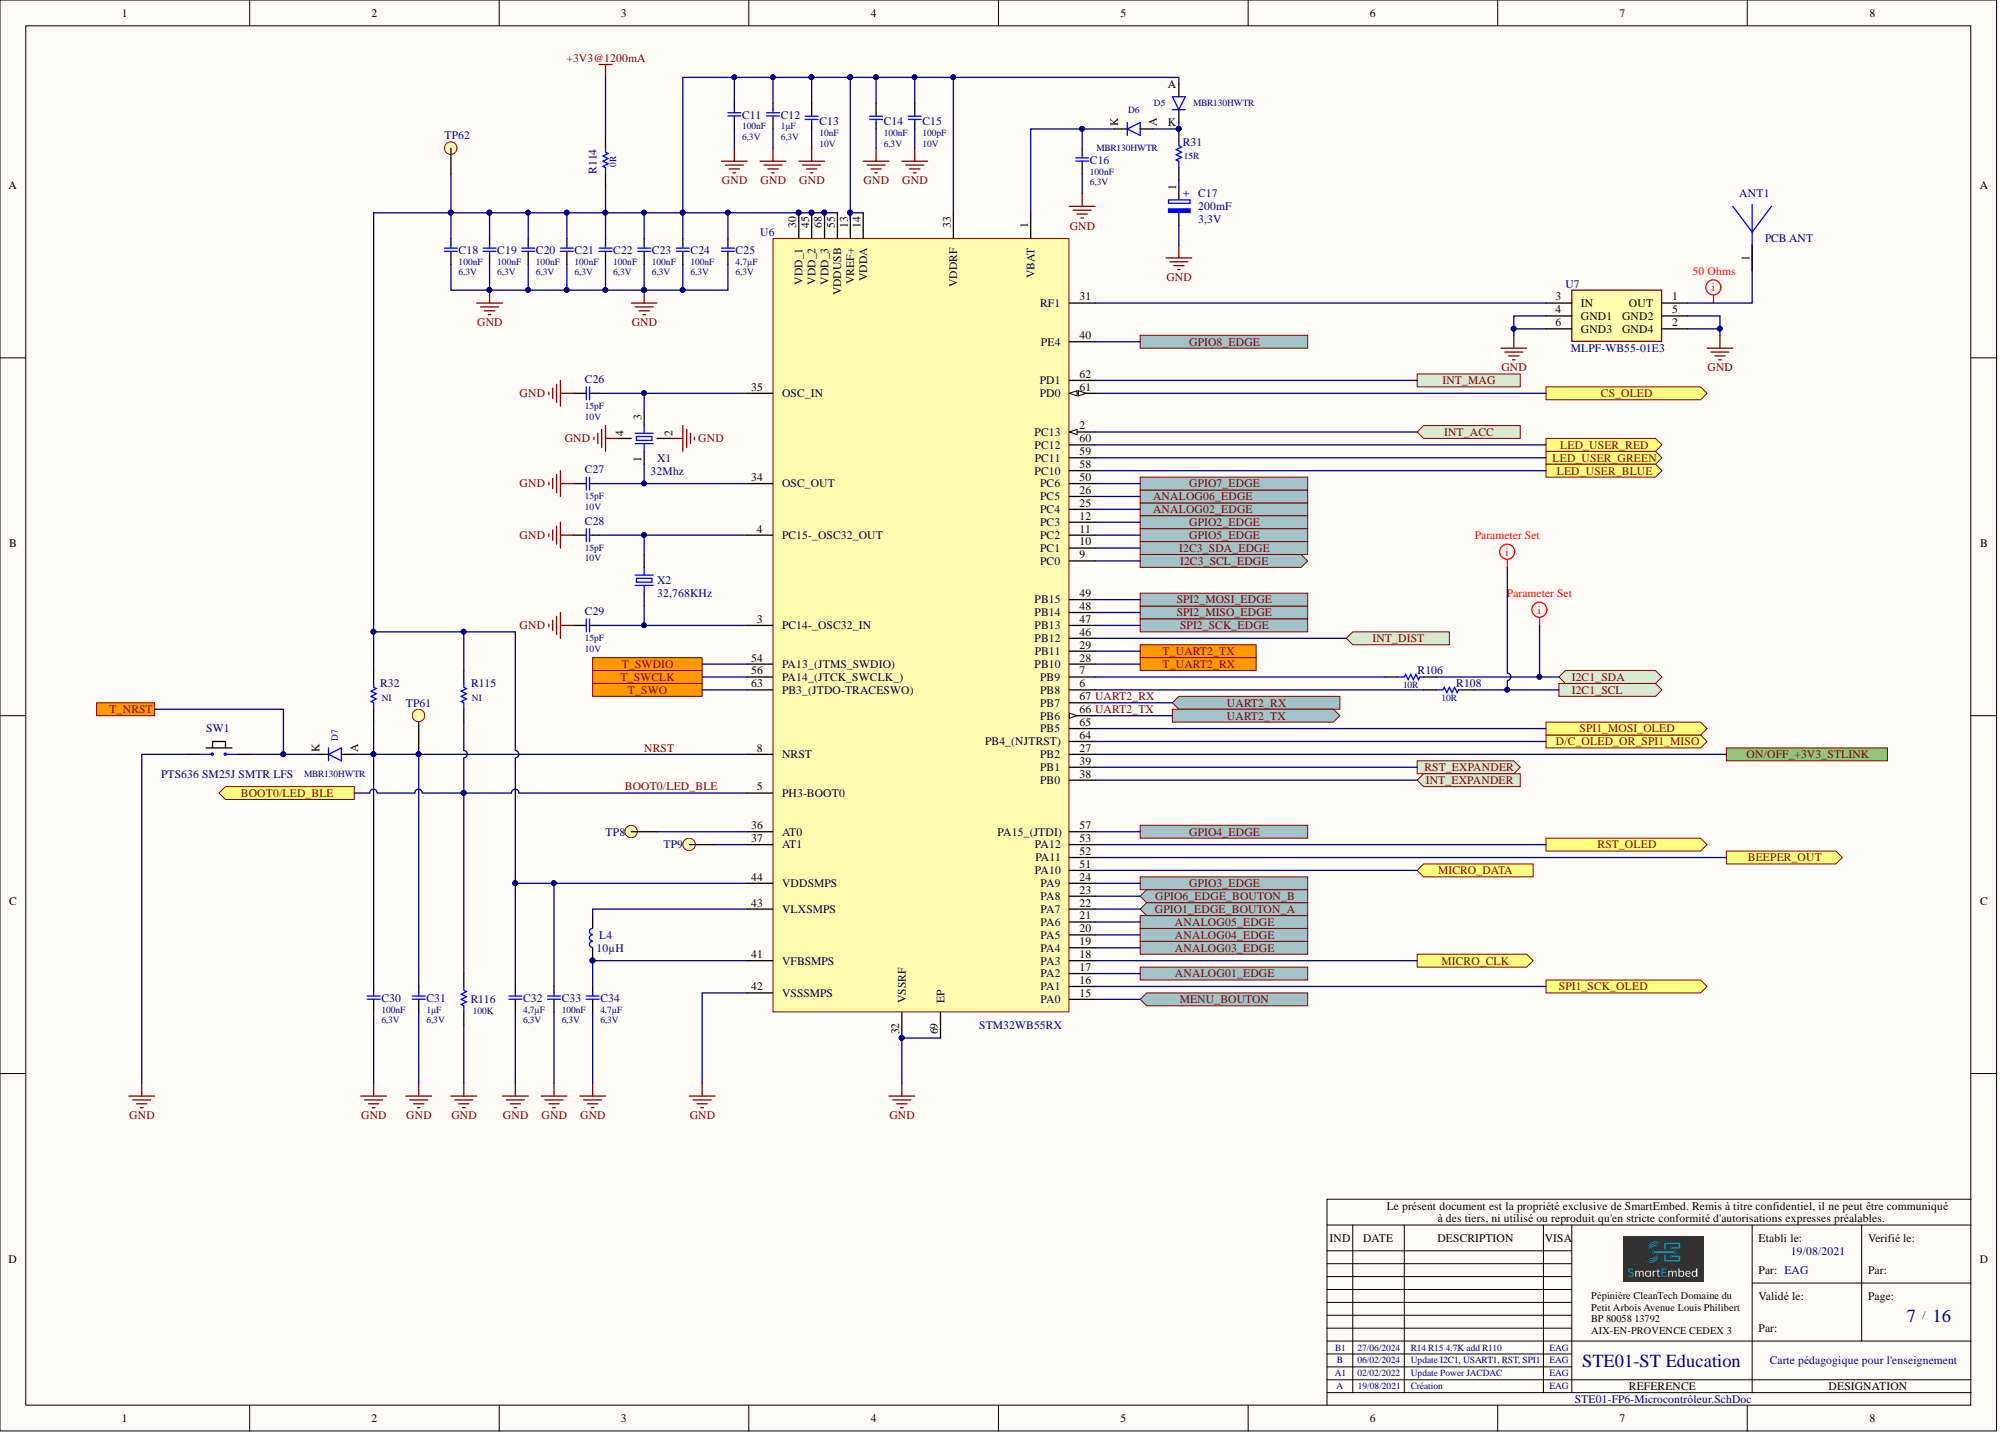
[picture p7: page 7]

BOOT0/LED_BLE | PH3-BOOT0 5

VLXSMPS 43

L4 | | | ANALOG05_EDGE

VFBSMPS 41

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

à des tiers, ni utilisé ou reproduit qu'en stricte conformité d'autorisations expresses préalables.

Pépinière CleanTech Domaine du
Petit Arbois Avenue Louis Philibert

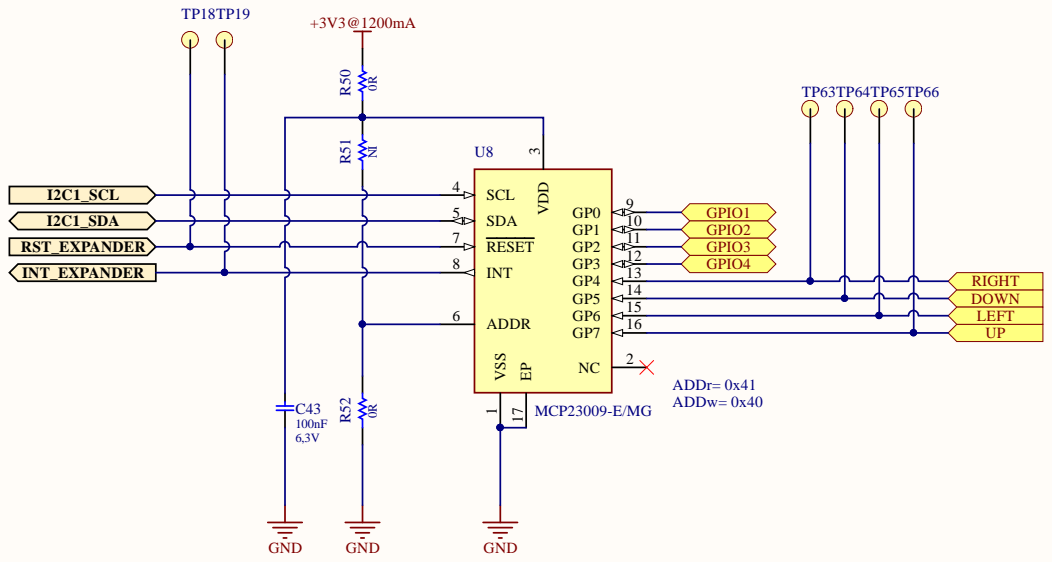
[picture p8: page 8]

5 | SCL SD A RESE T IN T A D D R

GPIO 1 GPIO 2 GPIO 3 GPIO 4

1 4
1 5

Val i d é le: | Page:

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

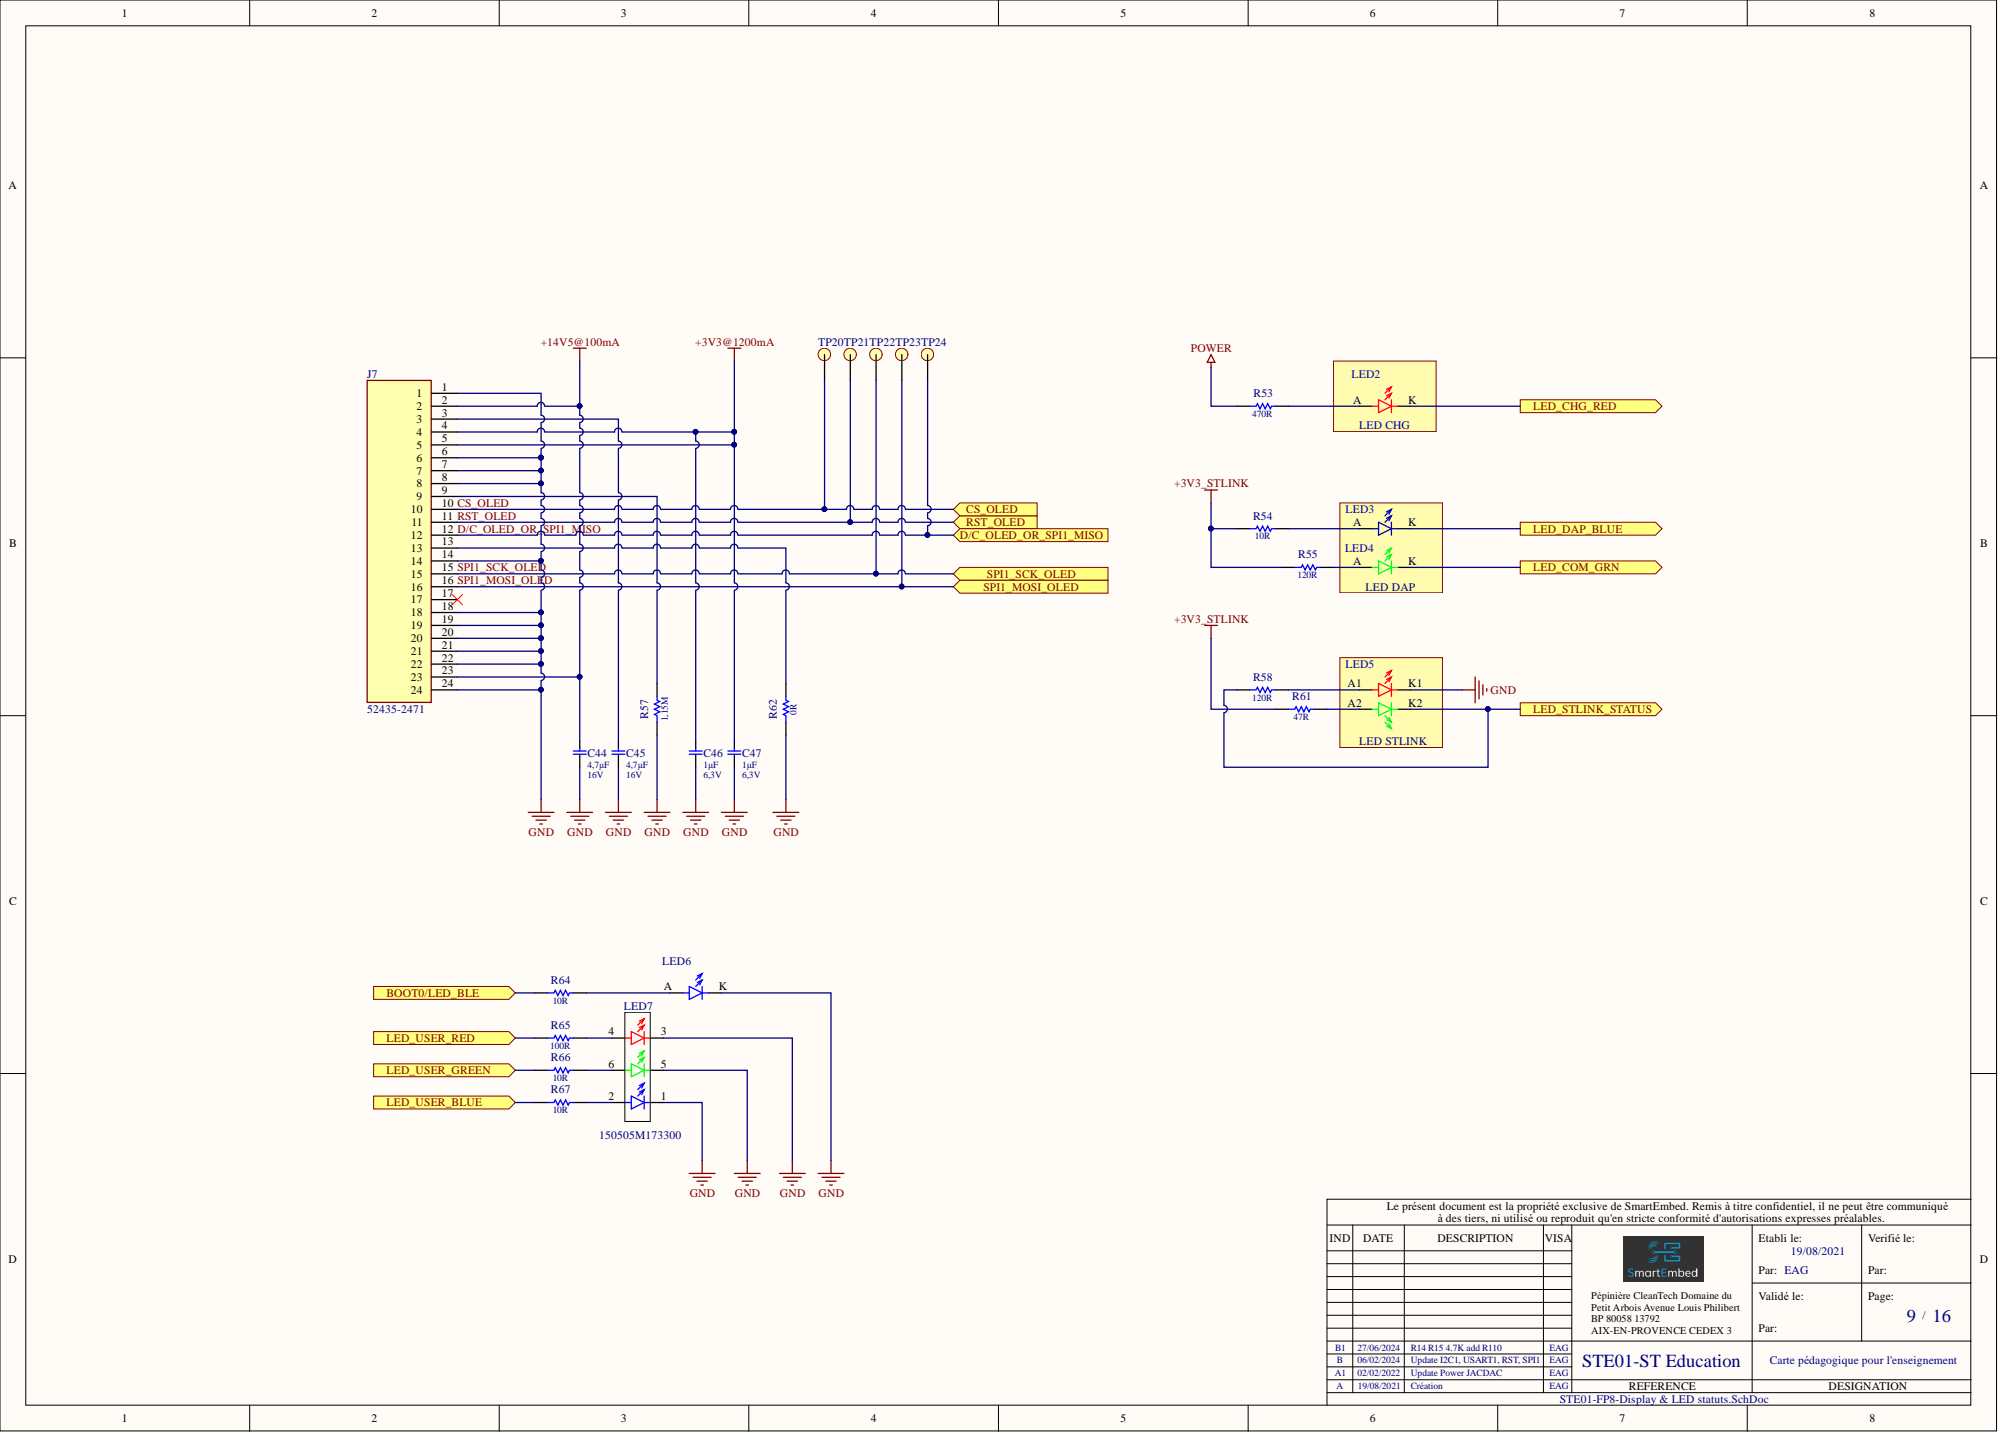
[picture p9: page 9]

SPI1_SCK_OLED
SPI1_MOSI_OLED

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

à des tiers, ni utilisé ou reproduit qu'en stricte conformité d'autorisations expresses préalables.

Pépinière CleanTech Domaine du
Petit Arbois Avenue Louis Philibert

STE01-FP8-Display & LED statuts.SchDoc

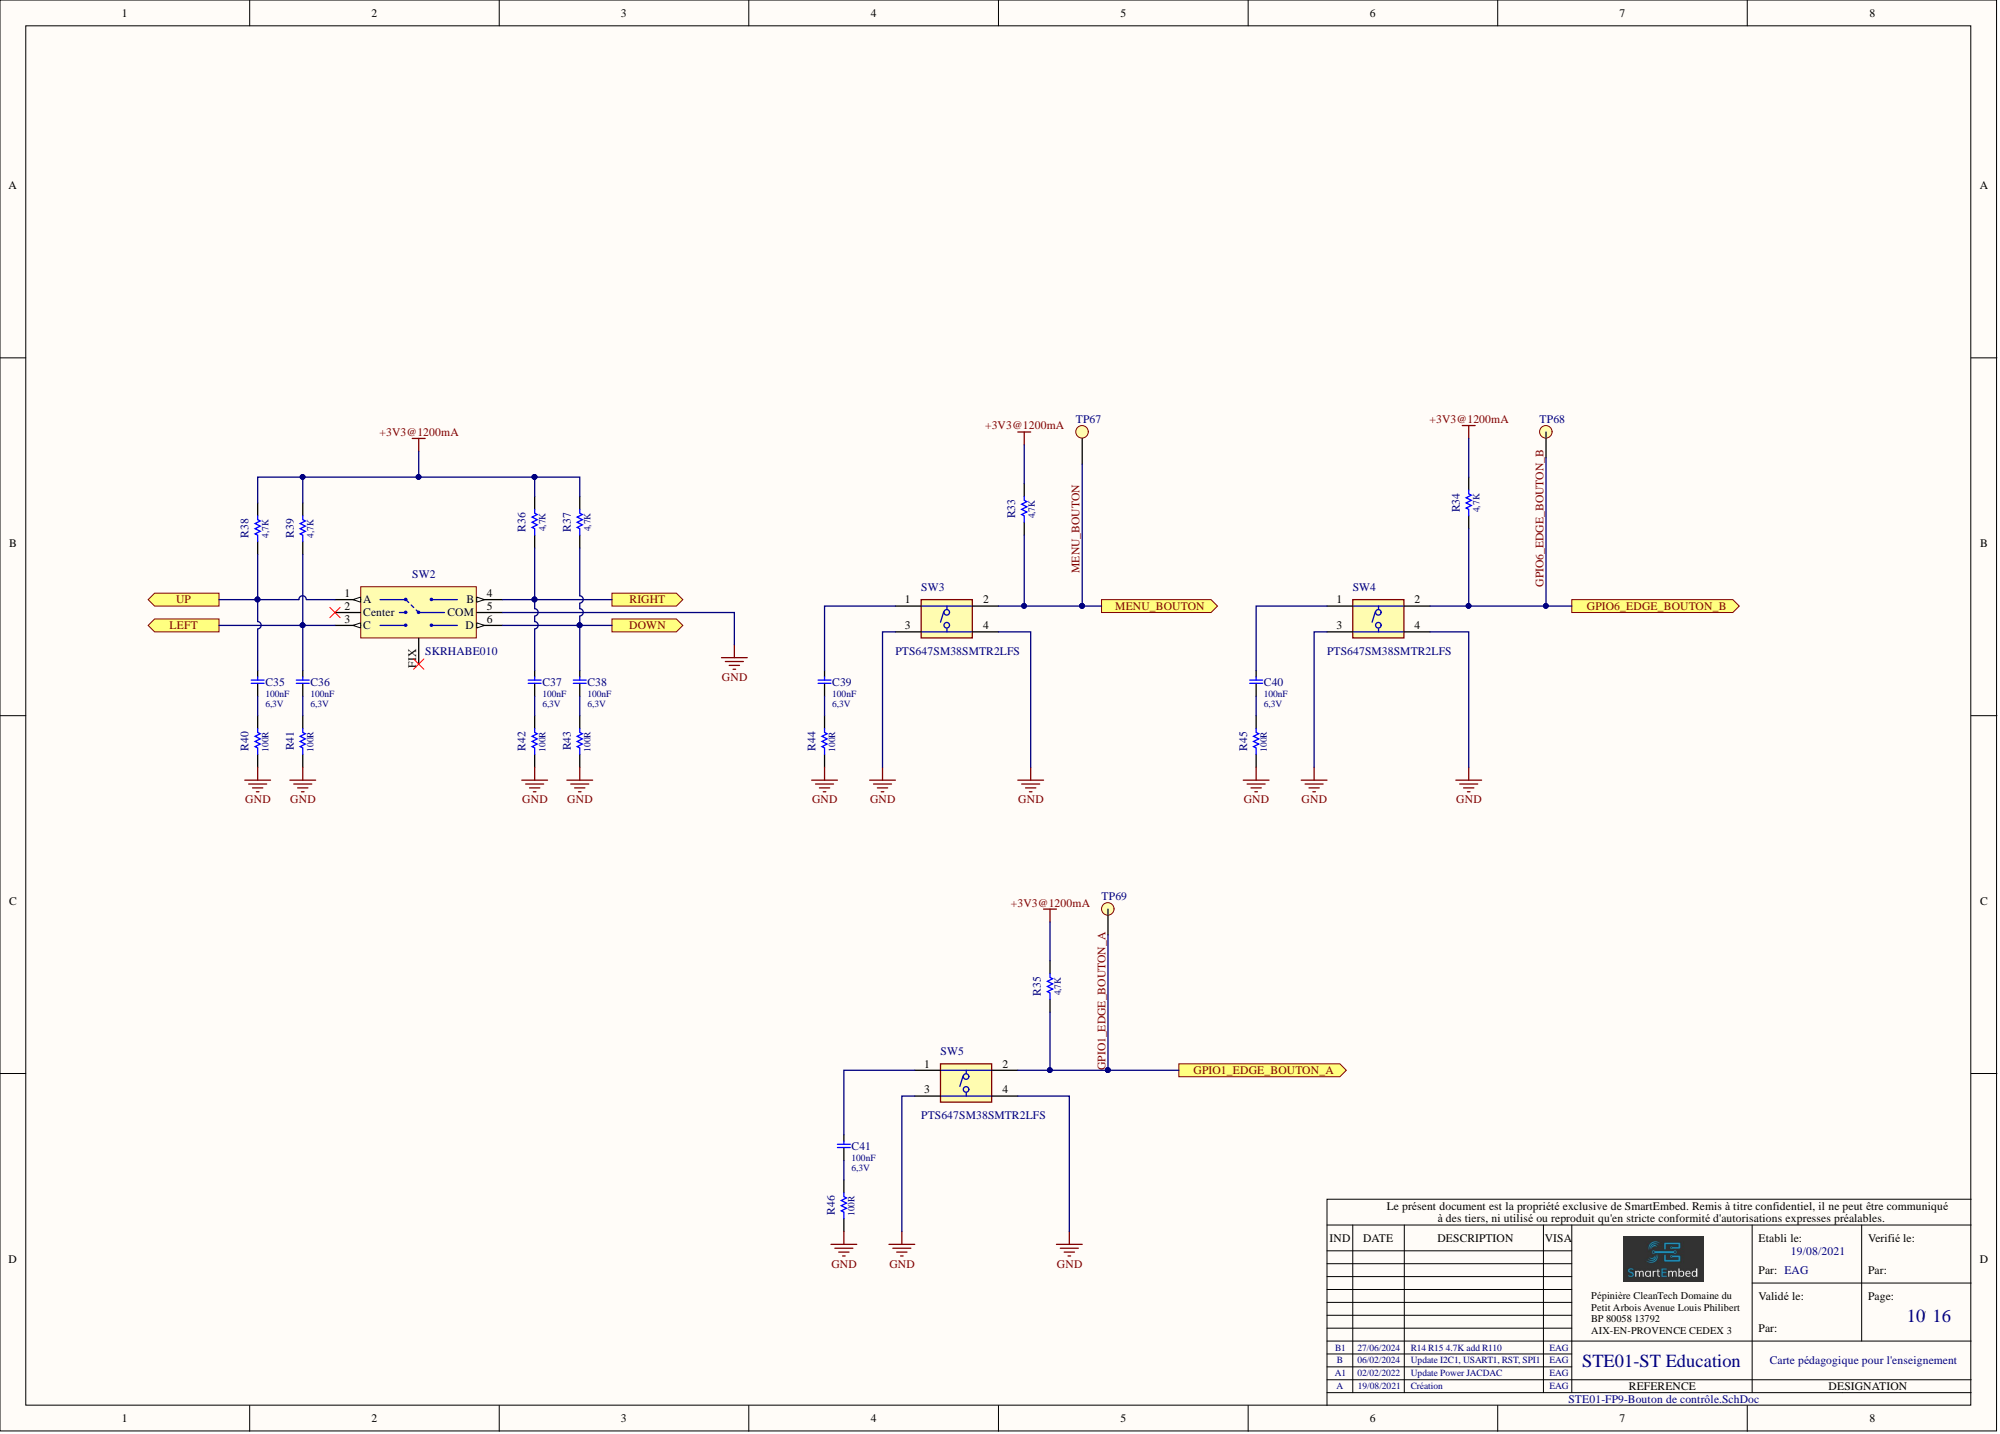
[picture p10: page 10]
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

à des tiers, ni utilisé ou reproduit qu'en stricte conformité d'autorisations expresses préalables.

Pépinière CleanTech Domaine du
Petit Arbois Avenue Louis Philibert

STE01-FP9-Bouton de contrôle.SchDoc

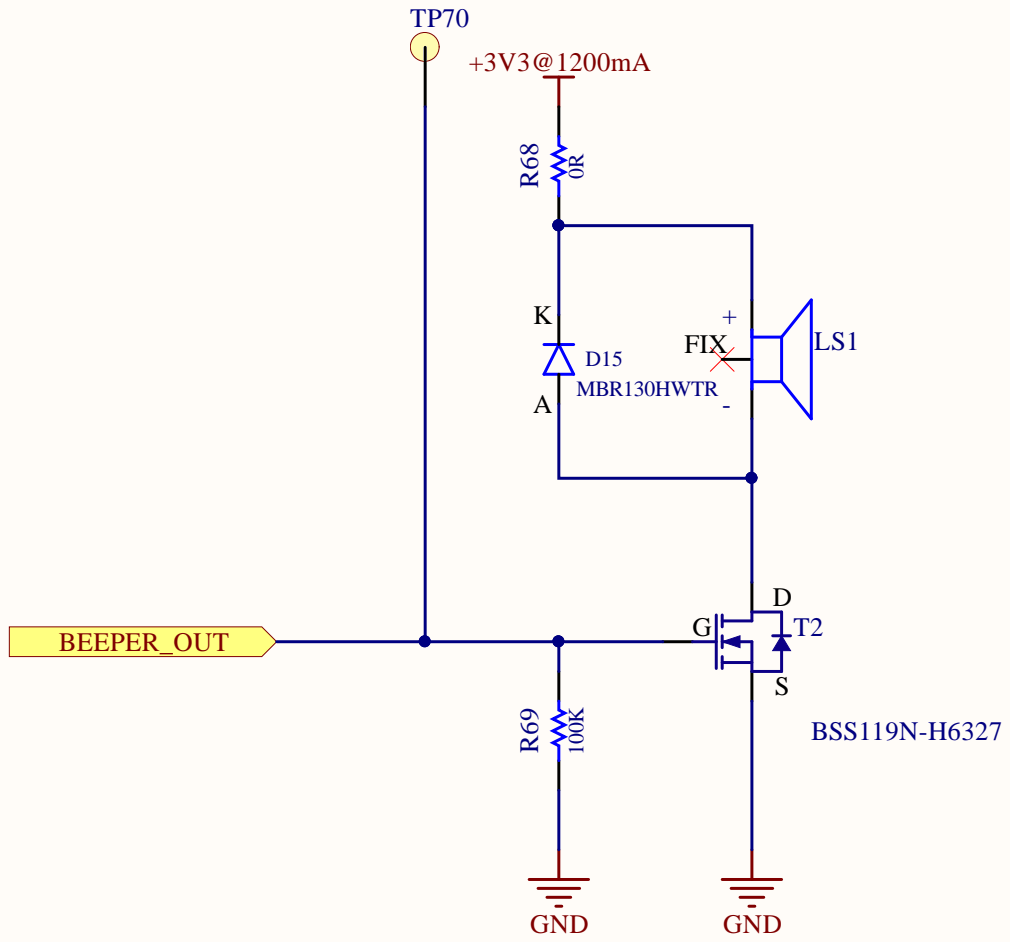
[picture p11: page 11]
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

à des tiers, ni utilisé ou reproduit qu'en stricte conformité d'autorisations expresses préalables.

Pépinière CleanTech Domaine du
Petit Arbois Avenue Louis Philibert

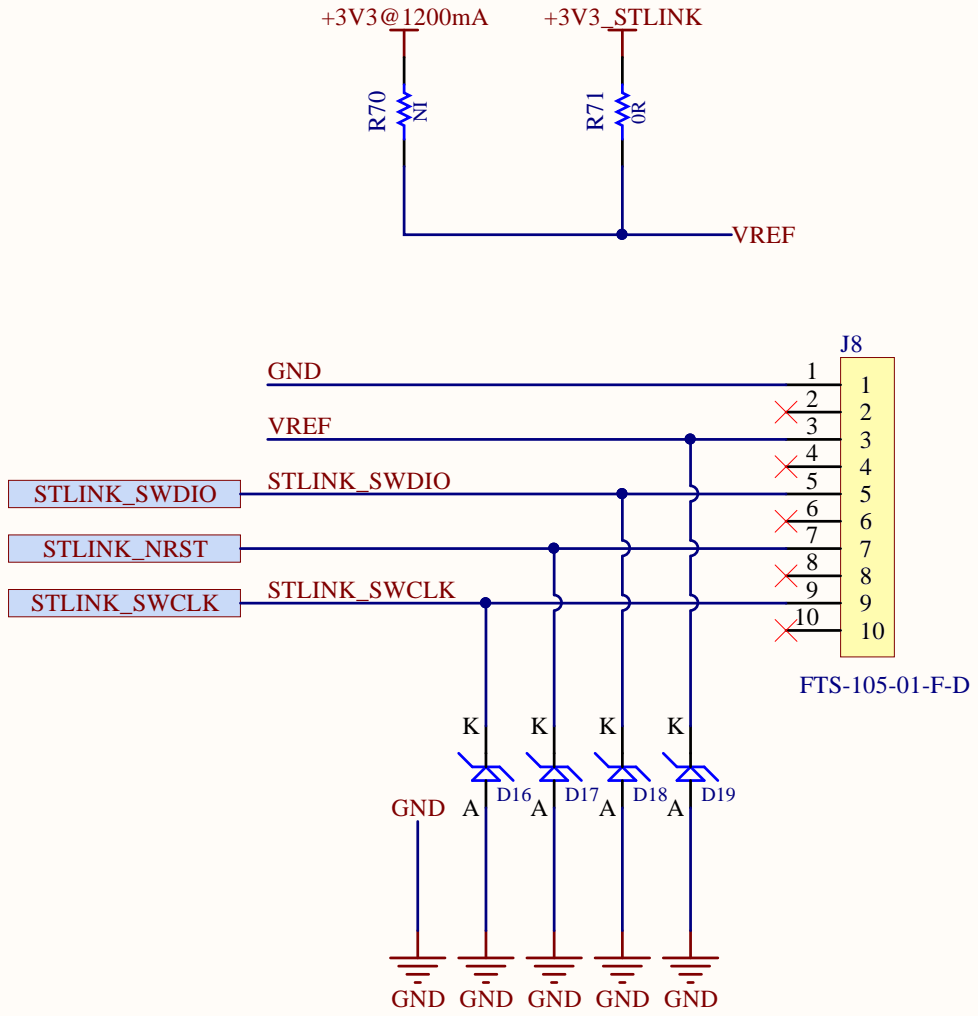
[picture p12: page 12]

GND GND

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

à des tiers, ni utilisé ou reproduit qu'en stricte conformité d'autorisations expresses préalables.
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



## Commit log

2024-09-26 Initial import of the final version of STeaMi
    [STeaMi-BOM.csv, STeaMi-BOM.xls, STeaMi-Pick_and_Place.csv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]
2024-10-01 chore: import altium design
    [STeaMi-FP1-Batterie.SchDoc, STeaMi-FP10-Sortie_Audio.SchDoc, STeaMi-FP11-Port_JTAG.SchDoc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]
